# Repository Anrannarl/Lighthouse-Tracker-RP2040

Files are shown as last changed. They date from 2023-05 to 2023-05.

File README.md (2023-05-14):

# Lighthouse-Tracker-RP2040
A Lighthouse tracker based on Raspberry Pi Pico.
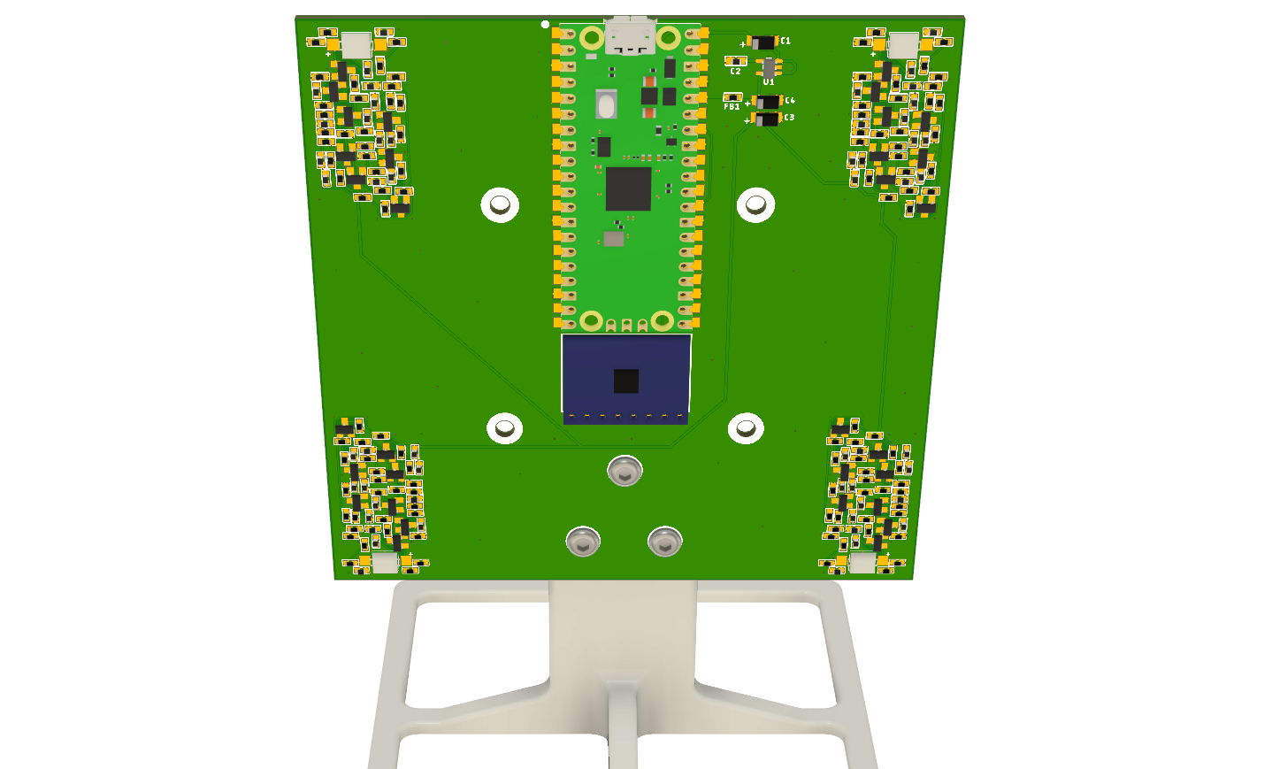
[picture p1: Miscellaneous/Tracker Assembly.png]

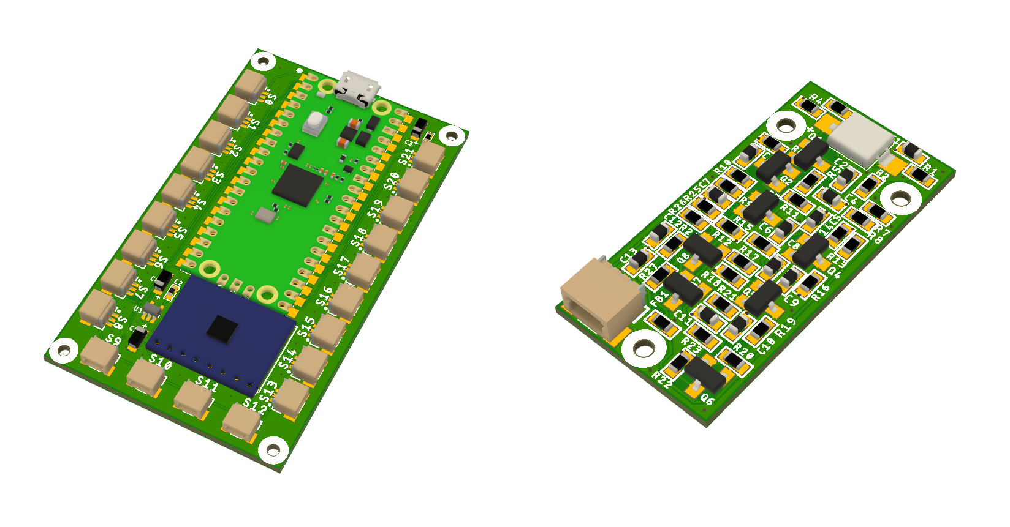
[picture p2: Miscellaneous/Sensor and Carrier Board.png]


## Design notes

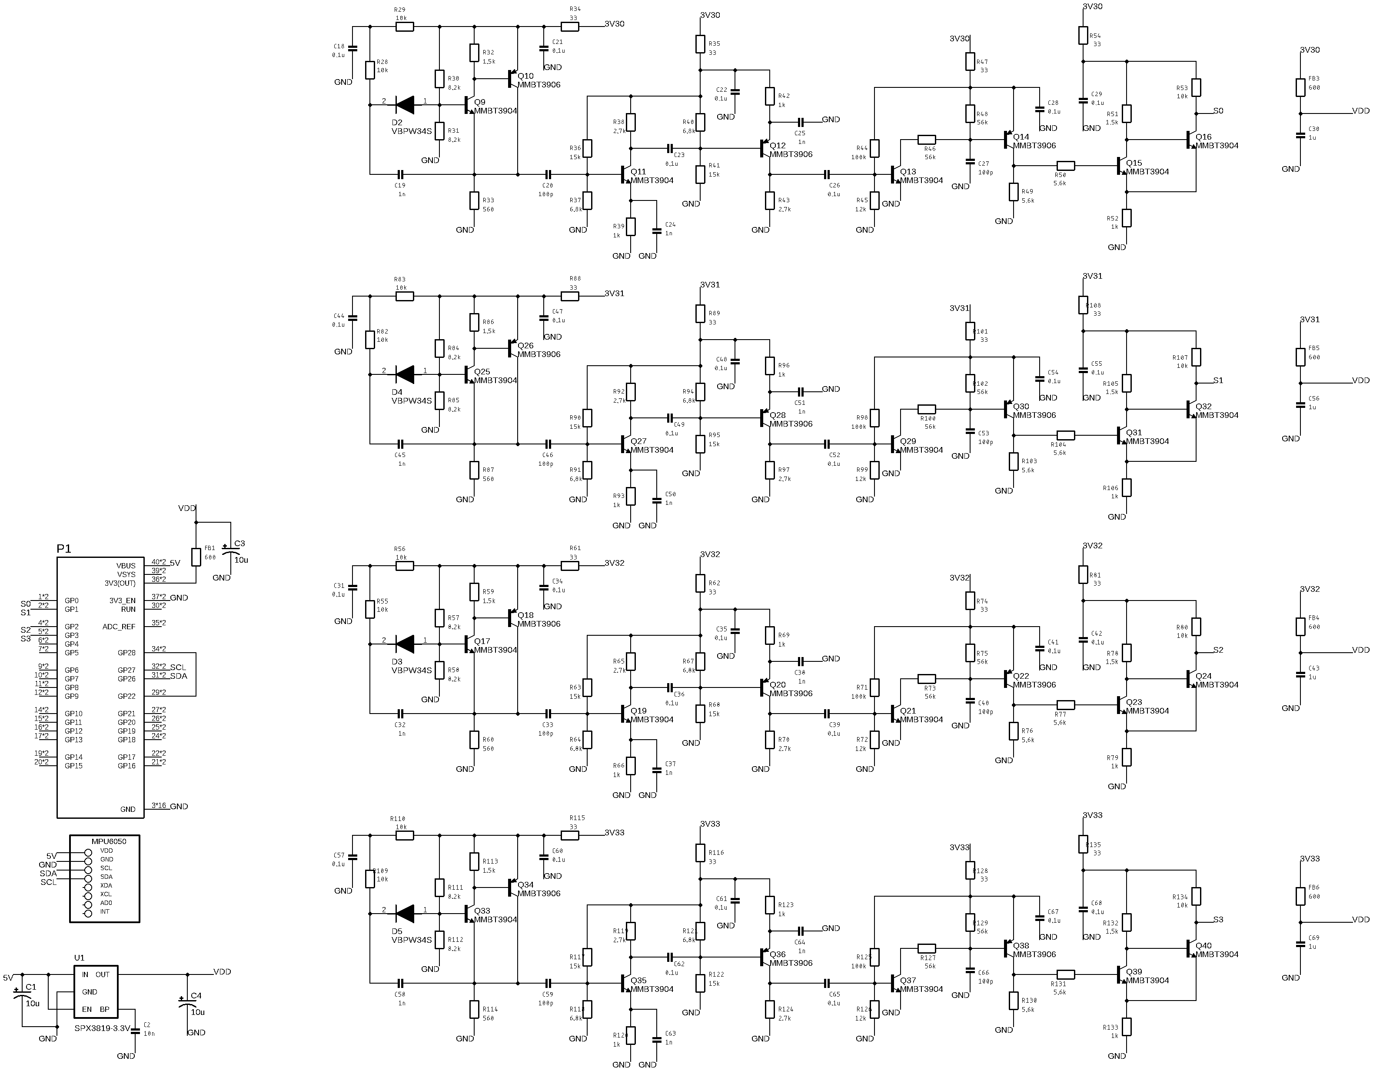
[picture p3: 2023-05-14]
Design Files/Lighthouse Tracker/Lighthouse Tracker.png

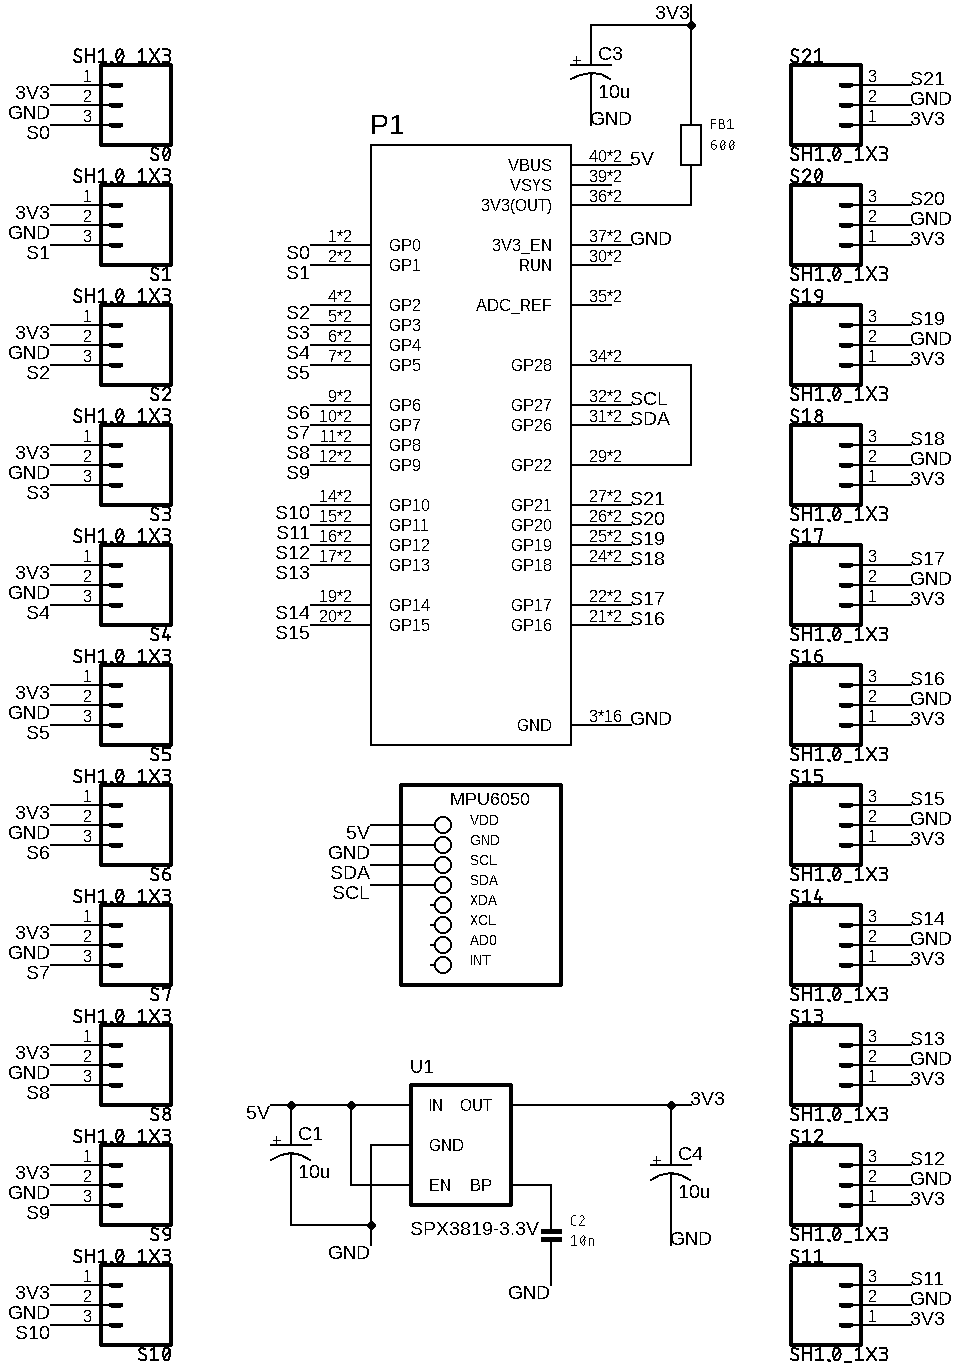
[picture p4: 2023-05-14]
Design Files/Lighthouse Sensor Carrier/Lighthouse Sensor Carrier.png

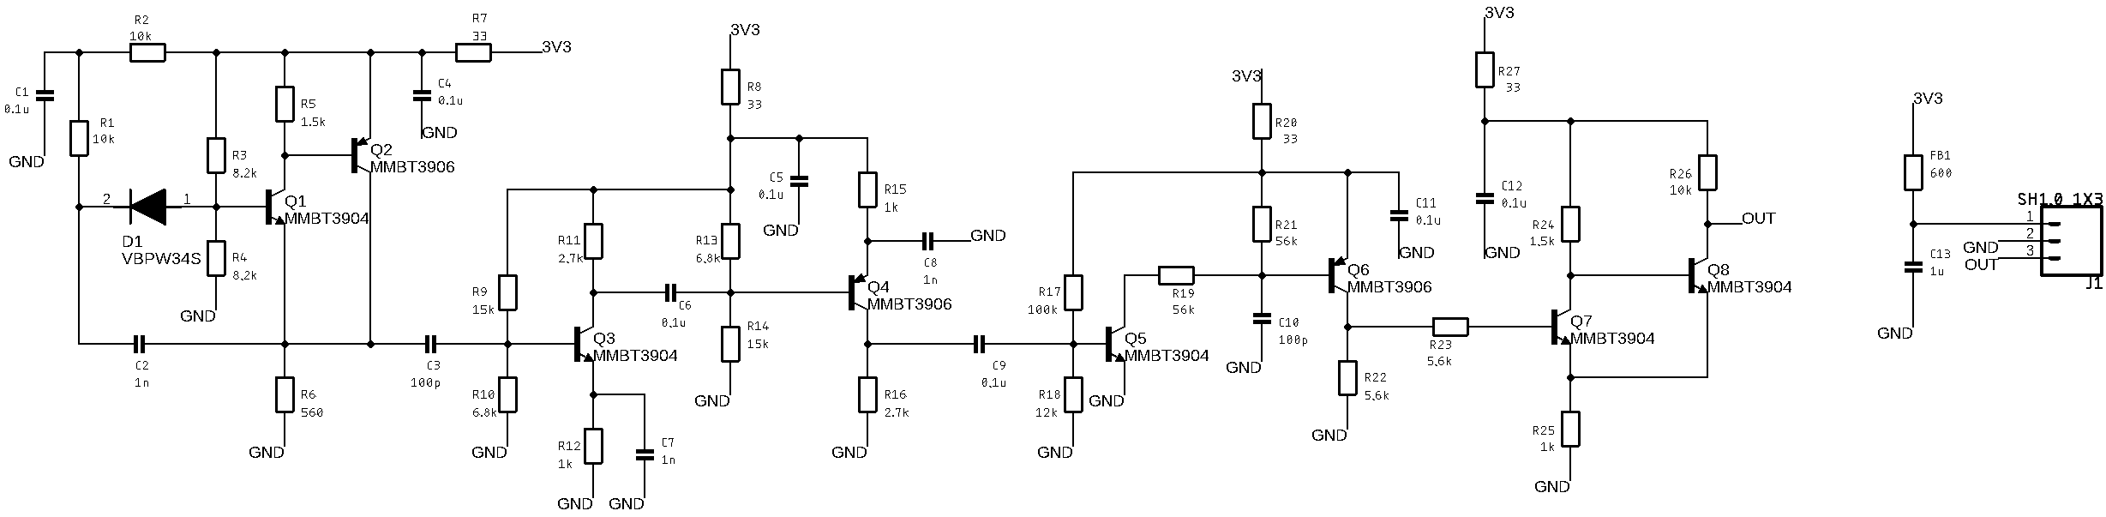
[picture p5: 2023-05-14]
Design Files/Lighthouse Sensor/Lighthouse Sensor.png

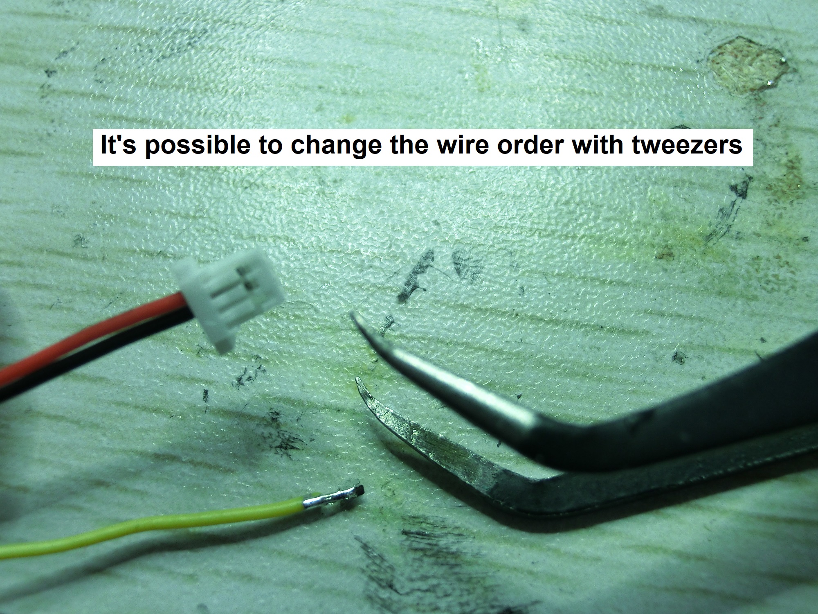
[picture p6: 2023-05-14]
Miscellaneous/Cable2.JPG

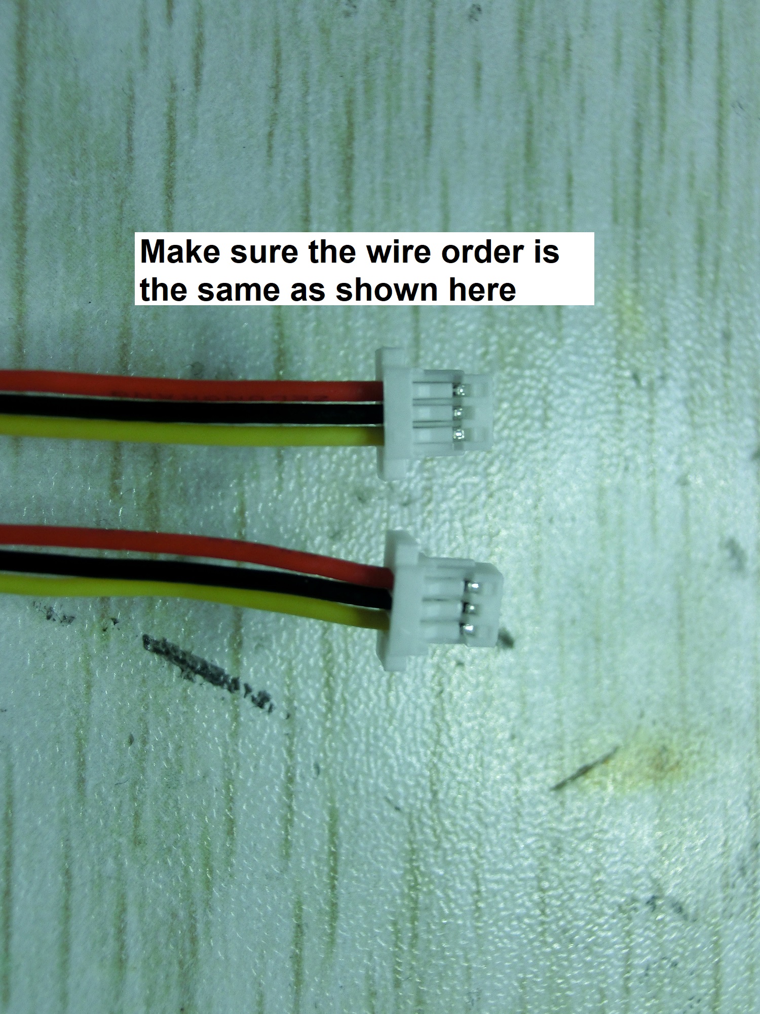
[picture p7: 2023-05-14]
Miscellaneous/Cable1.JPG

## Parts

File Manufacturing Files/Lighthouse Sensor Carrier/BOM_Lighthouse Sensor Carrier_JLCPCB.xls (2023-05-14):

Comment | Designator | Footprint | 嘉立创元件编号
10n | C2 | C0603 | C57112
10u | C1, C3, C4 | C3216 | C7171
600 | FB1 | R0603 | C1002
SPX3819-3.3V | U1 | SOT23-5 | C9055
SH1.0_1X3 | S0, S1, S2, S3, S4, S5, S6, S7, S8, S9, S10, S11, S12, S13, S14, S15, S16, S17, S18, S19, S20, S21 | 1X03_1MM_RA | C2936213

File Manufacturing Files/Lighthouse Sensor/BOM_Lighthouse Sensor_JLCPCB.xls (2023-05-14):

Comment | Designator | Footprint | 嘉立创元件编号
0.1u | C1, C4, C5, C6, C9, C11, C12 | C0603 | C14663
1.5k | R5, R24 | R0603 | C22843
100k | R17 | R0603 | C25803
100p | C3, C10 | C0603 | C14858
10k | R1, R2, R26 | R0603 | C25804
12k | R18 | R0603 | C22790
15k | R9, R14 | R0603 | C22809
1k | R12, R15, R25 | R0603 | C21190
1n | C2, C7, C8 | C0603 | C1588
1u | C13 | C0603 | C15849
2.7k | R11, R16 | R0603 | C13167
33 | R7, R8, R20, R27 | R0603 | C23140
5.6k | R22, R23 | R0603 | C23189
560 | R6 | R0603 | C23204
56k | R19, R21 | R0603 | C23206
6.8k | R10, R13 | R0603 | C23212
600 | FB1 | R0603 | C1002
8.2k | R3, R4 | R0603 | C25981
MMBT3904 | Q1, Q3, Q5, Q7, Q8 | SOT23 | C20526
MMBT3906 | Q2, Q4, Q6 | SOT23 | C2143
SH1.0_1X3 | J1 | 1X03_1MM_RA | C2936213
VBPW34S | D1 | VBPW34S | C131274

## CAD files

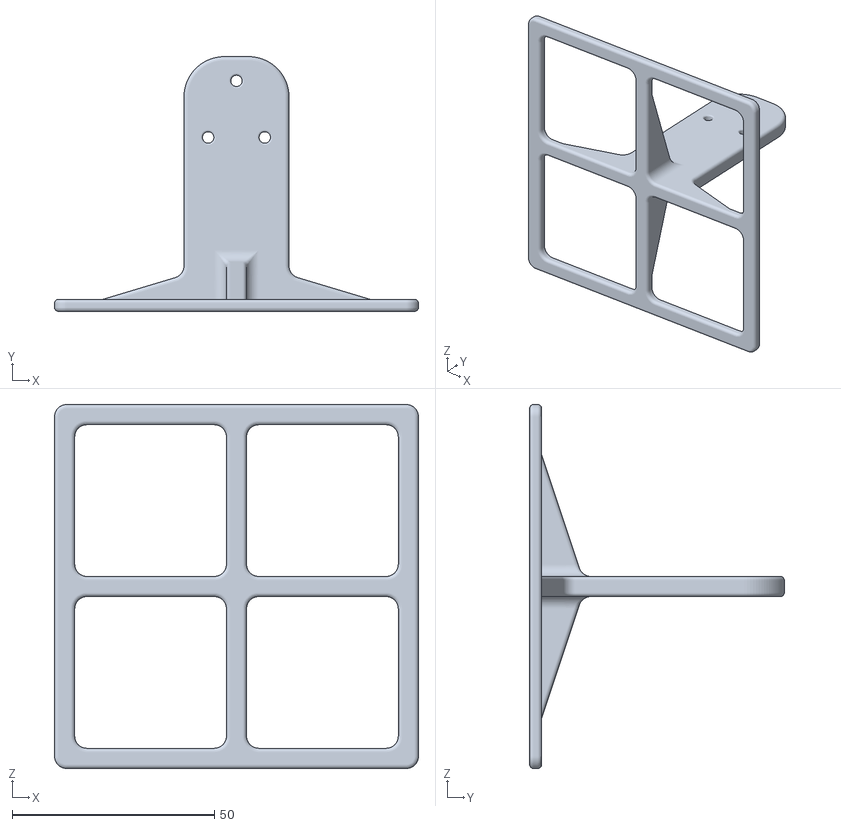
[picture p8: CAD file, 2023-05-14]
3D Models/Stand.stl
90.0 x 63.0 x 90.0

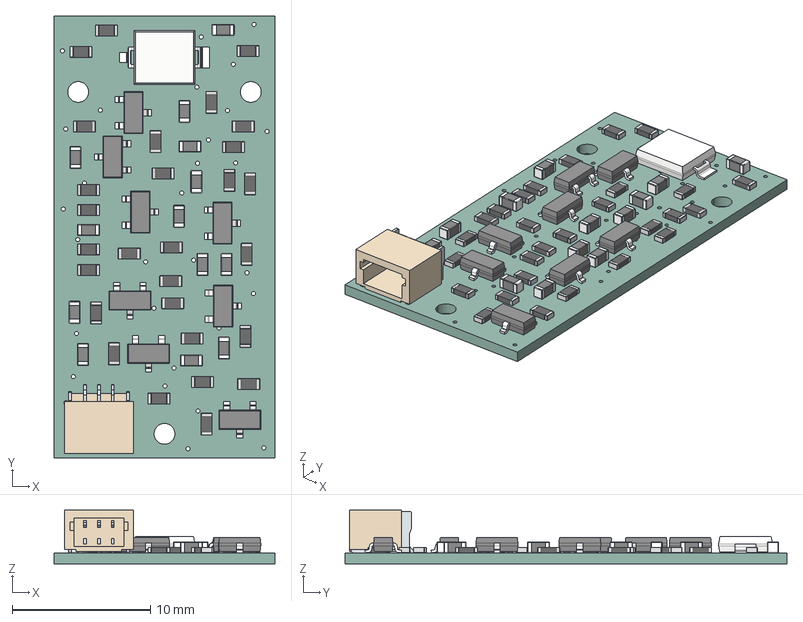
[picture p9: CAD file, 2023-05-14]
3D Models/Lighthouse Sensor.step
16.0 x 32.0 x 3.90 mm
Board
6651xx131822_PIN x 3
6651xx131822_PATTE x 2
Gehäuse x 13
Kontaktfläche x 26
R0603 x 28
SOT23-BEC x 5
SOT23-BEC (1) x 3

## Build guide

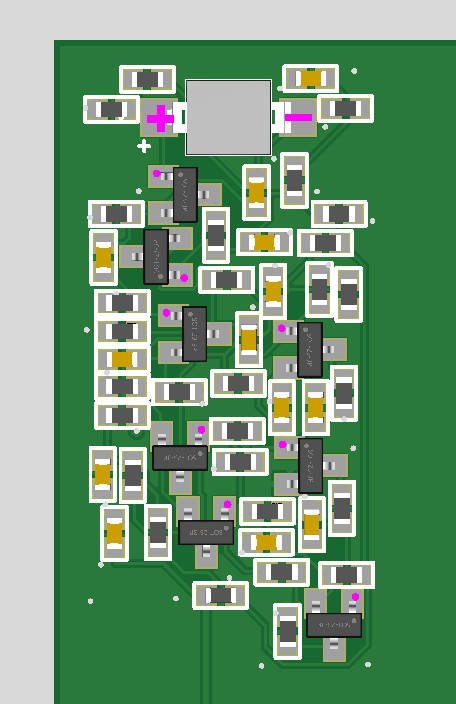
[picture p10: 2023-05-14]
Manufacturing Files/Lighthouse Tracker/Preview2.png

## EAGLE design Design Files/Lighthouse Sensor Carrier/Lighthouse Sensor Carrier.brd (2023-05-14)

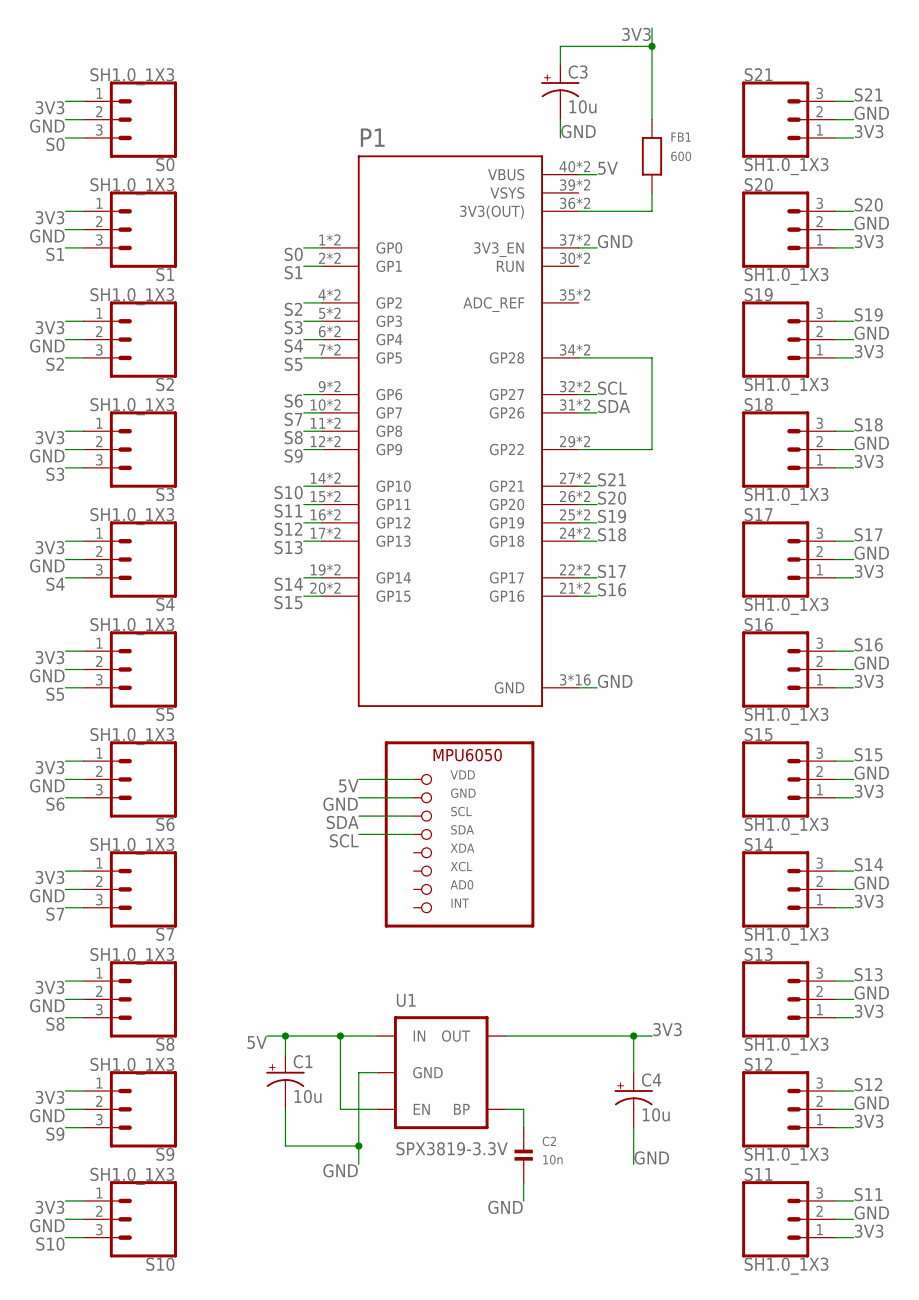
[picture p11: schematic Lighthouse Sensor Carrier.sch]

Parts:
C1, C3, C4: 10u; A/3216-18R
C2: 10n; 0603
FB1: 600; R0603
P1: RASPBERRY_PICO-NO_DEBUG; PICO-PKG-NO_DEBUG
S0, S1, S2, S3, S4, S5, S6, S7, S8, S9, S10, S11, S12, S13, S14, S15, S16, S17, S18, S19, S20, S21: SH1.0_1X3; 1X03_1MM_RA
U1: SPX3819-3.3V; SOT23-5
U$1: MPU6050BREAKOUT; MPU6050

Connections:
3V3: C3.+, C4.+, FB1.2, S0.1, S1.1, S2.1, S3.1, S4.1, S5.1, S6.1, S7.1, S8.1, S9.1, S10.1, S11.1, S12.1, S13.1, S14.1, S15.1, S16.1, S17.1, S18.1, S19.1, S20.1, S21.1, U1.5 (OUT)
5V: C1.+, P1.40 (VBUS), P1.P$40 (VBUS), U1.1 (IN), U1.3 (EN), U$1.VDD
GND: C1.-, C2.2, C3.-, C4.-, P1.3 (GND), P1.8 (GND), P1.13 (GND), P1.18 (GND), P1.23 (GND), P1.28 (GND), P1.33 (GND), P1.37 (3V3_EN), P1.38 (GND), P1.P$3 (GND), P1.P$8 (GND), P1.P$13 (GND), P1.P$18 (GND), P1.P$23 (GND), P1.P$28 (GND), P1.P$33 (GND), P1.P$37 (3V3_EN), P1.P$38 (GND), S0.2, S1.2, S2.2, S3.2, S4.2, S5.2, S6.2, S7.2, S8.2, S9.2, S10.2, S11.2, S12.2, S13.2, S14.2, S15.2, S16.2, S17.2, S18.2, S19.2, S20.2, S21.2, U1.2 (GND), U$1.GND
unnamed: C2.1, U1.4 (BP)
unnamed: FB1.1, P1.36 (3V3(OUT)), P1.P$36 (3V3(OUT))
unnamed: P1.29 (GP22), P1.34 (GP28), P1.P$29 (GP22), P1.P$34 (GP28)
S0: P1.1 (GP0), P1.P$1 (GP0), S0.3
S1: P1.2 (GP1), P1.P$2 (GP1), S1.3
S2: P1.4 (GP2), P1.P$4 (GP2), S2.3
S3: P1.5 (GP3), P1.P$5 (GP3), S3.3
S4: P1.6 (GP4), P1.P$6 (GP4), S4.3
S5: P1.7 (GP5), P1.P$7 (GP5), S5.3
S6: P1.9 (GP6), P1.P$9 (GP6), S6.3
S7: P1.10 (GP7), P1.P$10 (GP7), S7.3
S8: P1.11 (GP8), P1.P$11 (GP8), S8.3
S9: P1.12 (GP9), P1.P$12 (GP9), S9.3
S10: P1.14 (GP10), P1.P$14 (GP10), S10.3
S11: P1.15 (GP11), P1.P$15 (GP11), S11.3
S12: P1.16 (GP12), P1.P$16 (GP12), S12.3
S13: P1.17 (GP13), P1.P$17 (GP13), S13.3
S14: P1.19 (GP14), P1.P$19 (GP14), S14.3
S15: P1.20 (GP15), P1.P$20 (GP15), S15.3
S16: P1.21 (GP16), P1.P$21 (GP16), S16.3
S17: P1.22 (GP17), P1.P$22 (GP17), S17.3
S18: P1.24 (GP18), P1.P$24 (GP18), S18.3
S19: P1.25 (GP19), P1.P$25 (GP19), S19.3
S20: P1.26 (GP20), P1.P$26 (GP20), S20.3
S21: P1.27 (GP21), P1.P$27 (GP21), S21.3
SCL: P1.32 (GP27), P1.P$32 (GP27), U$1.SDA
SDA: P1.31 (GP26), P1.P$31 (GP26), U$1.SCL
VSYS: P1.39 (VSYS), P1.P$39 (VSYS)

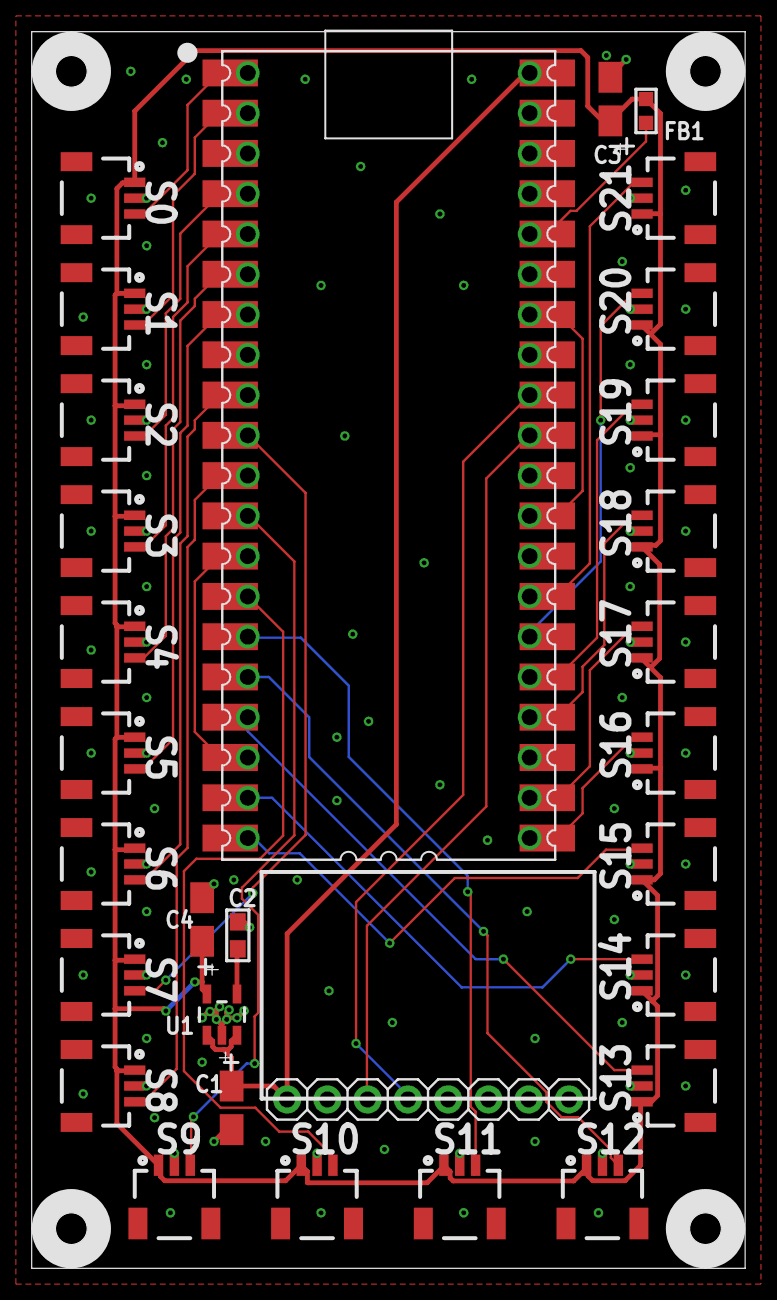
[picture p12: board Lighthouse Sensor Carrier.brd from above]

Board: 2 copper layers, 45.0 x 78.0 mm, 30 parts (0 on the bottom side), 31 nets.

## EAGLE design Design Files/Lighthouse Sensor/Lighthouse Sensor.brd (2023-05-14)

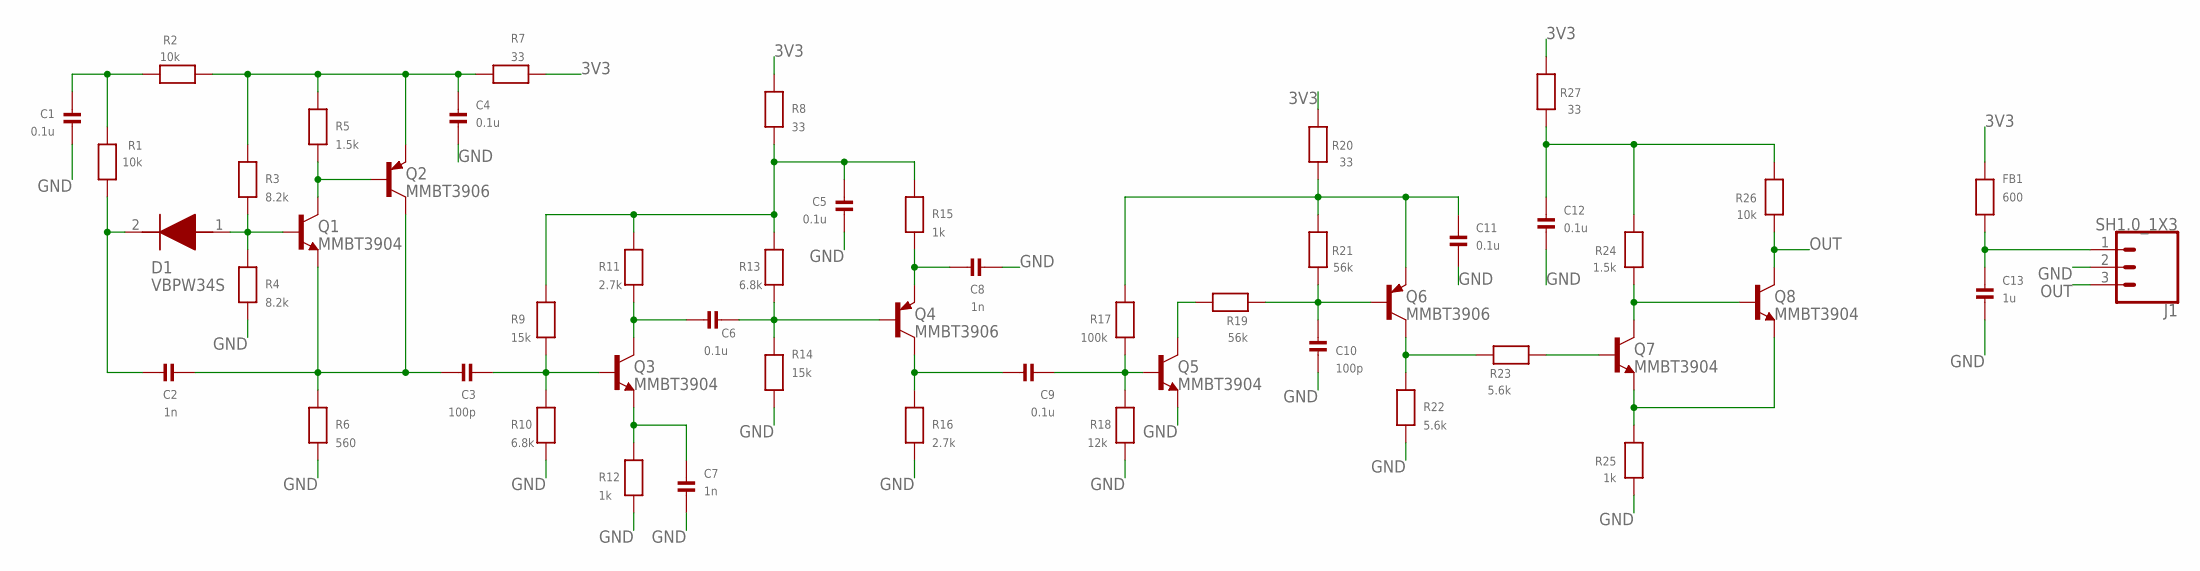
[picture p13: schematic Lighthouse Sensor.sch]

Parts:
C1, C4, C5, C6, C9, C11, C12: 0.1u; C0603
C2, C7, C8: 1n; C0603
C3, C10: 100p; C0603
C13: 1u; C0603
D1: VBPW34S
FB1: 600; R0603
J1: SH1.0_1X3; 1X03_1MM_RA
Q1, Q3, Q5, Q7, Q8: MMBT3904; SOT23-BEC
Q2, Q4, Q6: MMBT3906; SOT23-BEC
R1, R2, R26: 10k; R0603
R3, R4: 8.2k; R0603
R5, R24: 1.5k; R0603
R6: 560; R0603
R7, R8, R20, R27: 33; R0603
R9, R14: 15k; R0603
R10, R13: 6.8k; R0603
R11, R16: 2.7k; R0603
R12, R15, R25: 1k; R0603
R17: 100k; R0603
R18: 12k; R0603
R19, R21: 56k; R0603
R22, R23: 5.6k; R0603

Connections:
3V3: FB1.2, R7.2, R8.1, R20.2, R27.2
GND: C1.1, C4.1, C5.2, C7.2, C8.2, C10.1, C11.1, C12.1, C13.1, J1.2, Q5.E, R4.2, R6.2, R10.2, R12.2, R14.2, R16.2, R18.2, R22.1, R25.2
unnamed: C1.2, R1.2, R2.2
unnamed: C2.1, D1.2 (K), R1.1
unnamed: D1.1 (A), Q1.B, R3.2, R4.1
unnamed: C4.2, Q2.E, R2.1, R3.1, R5.1, R7.1
unnamed: Q1.C, Q2.B, R5.2
unnamed: C11.2, Q6.E, R17.1, R20.1, R21.2
unnamed: C5.1, R8.2, R9.1, R11.1, R13.1, R15.1
unnamed: C3.2, Q3.B, R9.2, R10.1
unnamed: C2.2, C3.1, Q1.E, Q2.C, R6.1
unnamed: C6.2, Q4.B, R13.2, R14.1
unnamed: C6.1, Q3.C, R11.2
unnamed: C7.1, Q3.E, R12.1
unnamed: C9.2, Q5.B, R17.2, R18.1
unnamed: C8.1, Q4.E, R15.2
unnamed: C9.1, Q4.C, R16.1
unnamed: Q6.C, R22.2, R23.2
unnamed: C10.2, Q6.B, R19.2, R21.1
unnamed: Q5.C, R19.1
unnamed: Q7.B, R23.1
unnamed: Q7.E, Q8.E, R25.1
unnamed: Q7.C, Q8.B, R24.2
unnamed: C13.2, FB1.1, J1.1
unnamed: C12.2, R24.1, R26.1, R27.1
OUT: J1.3, Q8.C, R26.2

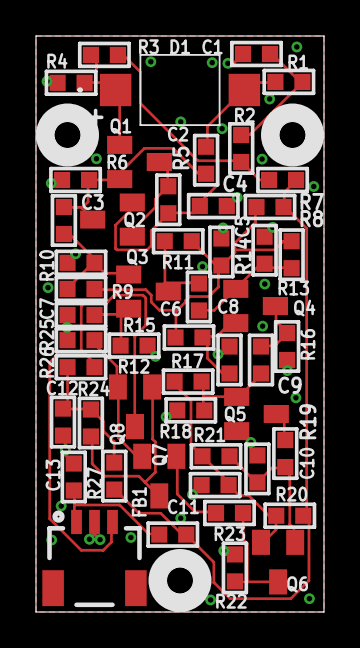
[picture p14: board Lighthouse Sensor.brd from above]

Board: 2 copper layers, 16.0 x 32.0 mm, 51 parts (0 on the bottom side), 26 nets.

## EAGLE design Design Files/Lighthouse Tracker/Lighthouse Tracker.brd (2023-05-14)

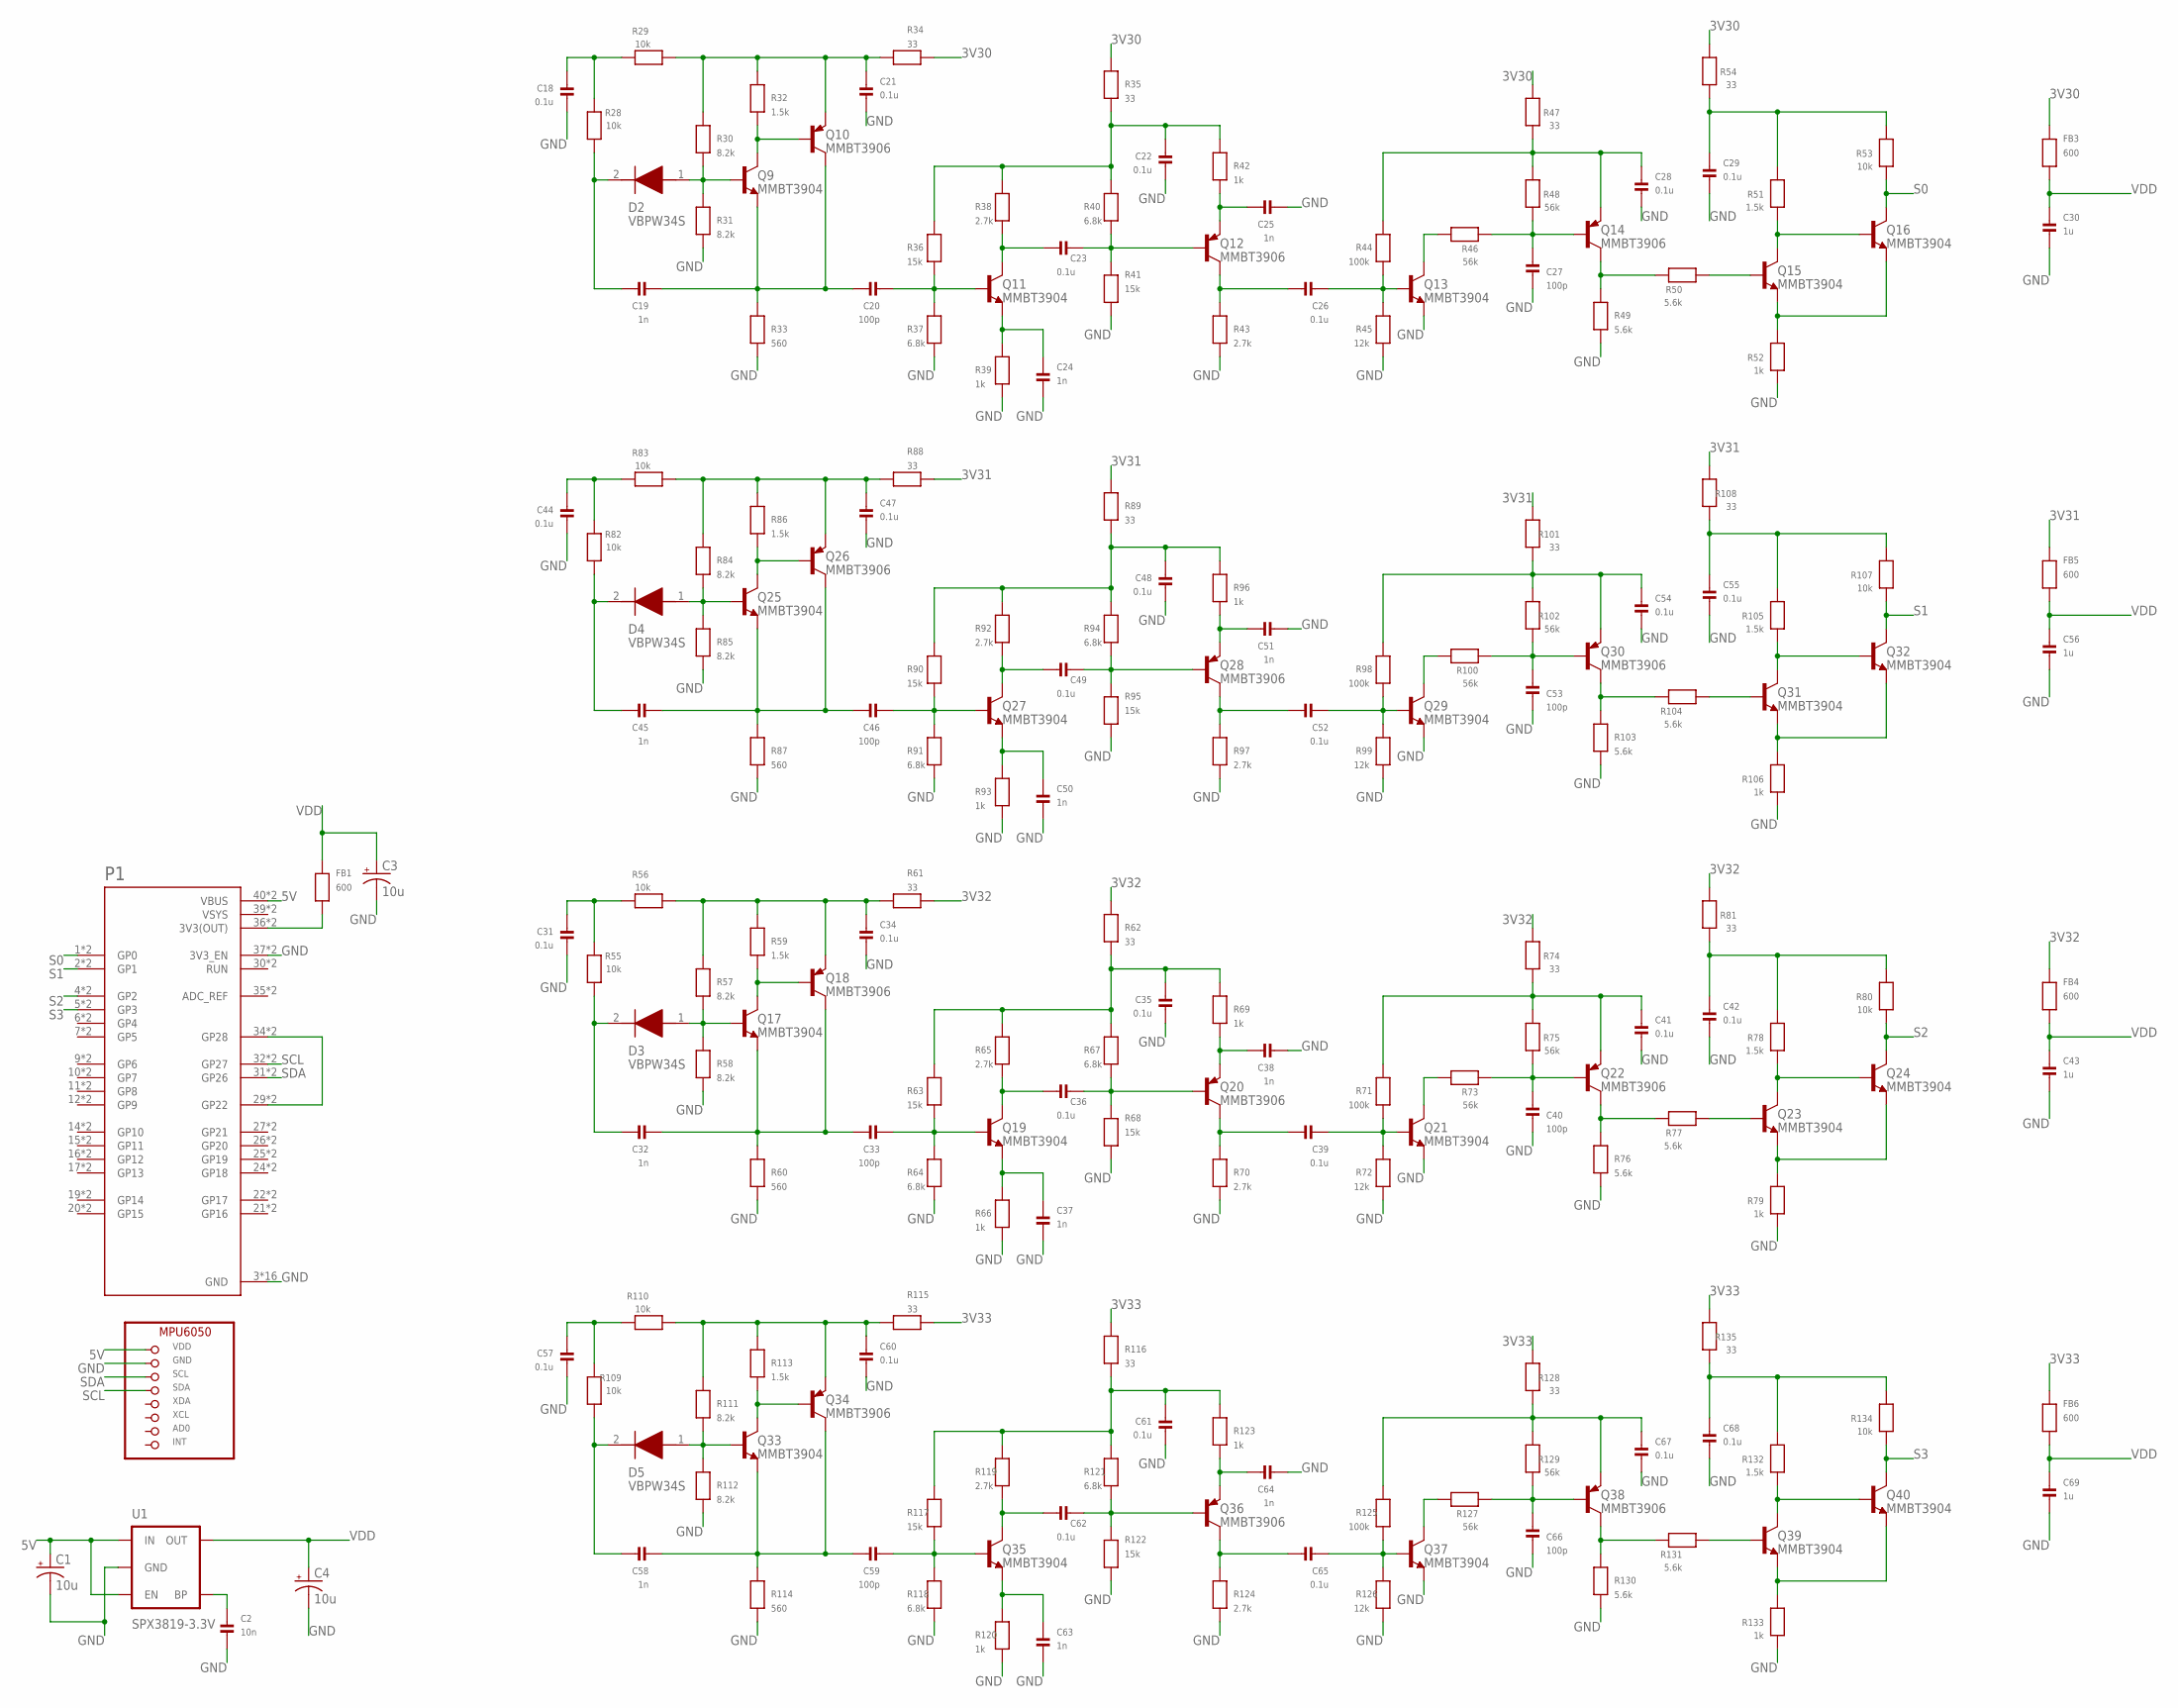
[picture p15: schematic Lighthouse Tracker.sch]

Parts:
B1: MPU6050BREAKOUT; MPU6050
C1, C3, C4: 10u; A/3216-18R
C2: 10n; 0603
C18, C21, C22, C23, C26, C28, C29, C31, C34, C35, C36, C39, C41, C42, C44, C47, C48, C49, C52, C54, C55, C57, C60, C61, C62, C65, C67, C68: 0.1u; C0603
C19, C24, C25, C32, C37, C38, C45, C50, C51, C58, C63, C64: 1n; C0603
C20, C27, C33, C40, C46, C53, C59, C66: 100p; C0603
C30, C43, C56, C69: 1u; C0603
D2, D3, D4, D5: VBPW34S
FB1, FB3, FB4, FB5, FB6: 600; R0603
P1: RASPBERRY_PICO-NO_DEBUG; PICO-PKG-NO_DEBUG
Q9, Q11, Q13, Q15, Q16, Q17, Q19, Q21, Q23, Q24, Q25, Q27, Q29, Q31, Q32, Q33, Q35, Q37, Q39, Q40: MMBT3904; SOT23-BEC
Q10, Q12, Q14, Q18, Q20, Q22, Q26, Q28, Q30, Q34, Q36, Q38: MMBT3906; SOT23-BEC
R28, R29, R53, R55, R56, R80, R82, R83, R107, R109, R110, R134: 10k; R0603
R30, R31, R57, R58, R84, R85, R111, R112: 8.2k; R0603
R32, R51, R59, R78, R86, R105, R113, R132: 1.5k; R0603
R33, R60, R87, R114: 560; R0603
R34, R35, R47, R54, R61, R62, R74, R81, R88, R89, R101, R108, R115, R116, R128, R135: 33; R0603
R36, R41, R63, R68, R90, R95, R117, R122: 15k; R0603
R37, R40, R64, R67, R91, R94, R118, R121: 6.8k; R0603
R38, R43, R65, R70, R92, R97, R119, R124: 2.7k; R0603
R39, R42, R52, R66, R69, R79, R93, R96, R106, R120, R123, R133: 1k; R0603
R44, R71, R98, R125: 100k; R0603
R45, R72, R99, R126: 12k; R0603
R46, R48, R73, R75, R100, R102, R127, R129: 56k; R0603
R49, R50, R76, R77, R103, R104, R130, R131: 5.6k; R0603
U1: SPX3819-3.3V; SOT23-5

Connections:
3V30: FB3.2, R34.2, R35.1, R47.2, R54.2
3V31: FB5.2, R88.2, R89.1, R101.2, R108.2
3V32: FB4.2, R61.2, R62.1, R74.2, R81.2
3V33: FB6.2, R115.2, R116.1, R128.2, R135.2
5V: B1.VDD, C1.+, P1.40 (VBUS), P1.P$40 (VBUS), U1.1 (IN), U1.3 (EN)
GND: B1.GND, C1.-, C2.2, C3.-, C4.-, C18.1, C21.1, C22.2, C24.2, C25.2, C27.1, C28.1, C29.1, C30.1, C31.1, C34.1, C35.2, C37.2, C38.2, C40.1, C41.1, C42.1, C43.1, C44.1, C47.1, C48.2, C50.2, C51.2, C53.1, C54.1, C55.1, C56.1, C57.1, C60.1, C61.2, C63.2, C64.2, C66.1, C67.1, C68.1, C69.1, P1.3 (GND), P1.8 (GND), P1.13 (GND), P1.18 (GND), P1.23 (GND), P1.28 (GND), P1.33 (GND), P1.37 (3V3_EN), P1.38 (GND), P1.P$3 (GND), P1.P$8 (GND), P1.P$13 (GND), P1.P$18 (GND), P1.P$23 (GND), P1.P$28 (GND), P1.P$33 (GND), P1.P$37 (3V3_EN), P1.P$38 (GND), Q13.E, Q21.E, Q29.E, Q37.E, R31.2, R33.2, R37.2, R39.2, R41.2, R43.2, R45.2, R49.1, R52.2, R58.2, R60.2, R64.2, R66.2, R68.2, R70.2, R72.2, R76.1, R79.2, R85.2, R87.2, R91.2, R93.2, R95.2, R97.2, R99.2, R103.1, R106.2, R112.2, R114.2, R118.2, R120.2, R122.2, R124.2, R126.2, R130.1, R133.2, U1.2 (GND)
unnamed: C2.1, U1.4 (BP)
unnamed: FB1.1, P1.36 (3V3(OUT)), P1.P$36 (3V3(OUT))
unnamed: P1.29 (GP22), P1.34 (GP28), P1.P$29 (GP22), P1.P$34 (GP28)
unnamed: C18.2, R28.2, R29.2
unnamed: C19.1, D2.2 (K), R28.1
unnamed: D2.1 (A), Q9.B, R30.2, R31.1
unnamed: C21.2, Q10.E, R29.1, R30.1, R32.1, R34.1
unnamed: Q9.C, Q10.B, R32.2
unnamed: C19.2, C20.1, Q9.E, Q10.C, R33.1
unnamed: C22.1, R35.2, R36.1, R38.1, R40.1, R42.1
unnamed: C20.2, Q11.B, R36.2, R37.1
unnamed: C23.1, Q11.C, R38.2
unnamed: C24.1, Q11.E, R39.1
unnamed: C23.2, Q12.B, R40.2, R41.1
unnamed: C25.1, Q12.E, R42.2
unnamed: C26.1, Q12.C, R43.1
unnamed: C26.2, Q13.B, R44.2, R45.1
unnamed: C28.2, Q14.E, R44.1, R47.1, R48.2
unnamed: C27.2, Q14.B, R46.2, R48.1
unnamed: Q13.C, R46.1
unnamed: Q14.C, R49.2, R50.2
unnamed: Q15.B, R50.1
unnamed: Q15.E, Q16.E, R52.1
unnamed: Q15.C, Q16.B, R51.2
unnamed: C29.2, R51.1, R53.1, R54.1
unnamed: C31.2, R55.2, R56.2
unnamed: C32.1, D3.2 (K), R55.1
unnamed: D3.1 (A), Q17.B, R57.2, R58.1
unnamed: C34.2, Q18.E, R56.1, R57.1, R59.1, R61.1
unnamed: Q17.C, Q18.B, R59.2
unnamed: C32.2, C33.1, Q17.E, Q18.C, R60.1
unnamed: C35.1, R62.2, R63.1, R65.1, R67.1, R69.1
unnamed: C33.2, Q19.B, R63.2, R64.1
unnamed: C36.1, Q19.C, R65.2
unnamed: C37.1, Q19.E, R66.1
unnamed: C36.2, Q20.B, R67.2, R68.1
unnamed: C38.1, Q20.E, R69.2
unnamed: C39.1, Q20.C, R70.1
unnamed: C39.2, Q21.B, R71.2, R72.1
unnamed: C41.2, Q22.E, R71.1, R74.1, R75.2
unnamed: C40.2, Q22.B, R73.2, R75.1
unnamed: Q21.C, R73.1
unnamed: Q22.C, R76.2, R77.2
unnamed: Q23.B, R77.1
unnamed: Q23.E, Q24.E, R79.1
unnamed: Q23.C, Q24.B, R78.2
unnamed: C42.2, R78.1, R80.1, R81.1
unnamed: C44.2, R82.2, R83.2
unnamed: C45.1, D4.2 (K), R82.1
unnamed: D4.1 (A), Q25.B, R84.2, R85.1
unnamed: C47.2, Q26.E, R83.1, R84.1, R86.1, R88.1
unnamed: Q25.C, Q26.B, R86.2
unnamed: C45.2, C46.1, Q25.E, Q26.C, R87.1
unnamed: C48.1, R89.2, R90.1, R92.1, R94.1, R96.1
unnamed: C46.2, Q27.B, R90.2, R91.1
unnamed: C49.1, Q27.C, R92.2
unnamed: C50.1, Q27.E, R93.1
unnamed: C49.2, Q28.B, R94.2, R95.1
unnamed: C51.1, Q28.E, R96.2
unnamed: C52.1, Q28.C, R97.1
unnamed: C52.2, Q29.B, R98.2, R99.1
unnamed: C54.2, Q30.E, R98.1, R101.1, R102.2
unnamed: C53.2, Q30.B, R100.2, R102.1
unnamed: Q29.C, R100.1
unnamed: Q30.C, R103.2, R104.2
unnamed: Q31.B, R104.1
unnamed: Q31.E, Q32.E, R106.1
unnamed: Q31.C, Q32.B, R105.2
unnamed: C55.2, R105.1, R107.1, R108.1
unnamed: C57.2, R109.2, R110.2
unnamed: C58.1, D5.2 (K), R109.1
unnamed: D5.1 (A), Q33.B, R111.2, R112.1
unnamed: C60.2, Q34.E, R110.1, R111.1, R113.1, R115.1
unnamed: Q33.C, Q34.B, R113.2
unnamed: C58.2, C59.1, Q33.E, Q34.C, R114.1
unnamed: C61.1, R116.2, R117.1, R119.1, R121.1, R123.1
unnamed: C59.2, Q35.B, R117.2, R118.1
unnamed: C62.1, Q35.C, R119.2
unnamed: C63.1, Q35.E, R120.1
unnamed: C62.2, Q36.B, R121.2, R122.1
unnamed: C64.1, Q36.E, R123.2
unnamed: C65.1, Q36.C, R124.1
unnamed: C65.2, Q37.B, R125.2, R126.1
unnamed: C67.2, Q38.E, R125.1, R128.1, R129.2
unnamed: C66.2, Q38.B, R127.2, R129.1
unnamed: Q37.C, R127.1
unnamed: Q38.C, R130.2, R131.2
unnamed: Q39.B, R131.1
unnamed: Q39.E, Q40.E, R133.1
unnamed: Q39.C, Q40.B, R132.2
unnamed: C68.2, R132.1, R134.1, R135.1
S0: P1.1 (GP0), P1.P$1 (GP0), Q16.C, R53.2
S1: P1.2 (GP1), P1.P$2 (GP1), Q32.C, R107.2
S2: P1.4 (GP2), P1.P$4 (GP2), Q24.C, R80.2
S3: P1.5 (GP3), P1.P$5 (GP3), Q40.C, R134.2
SCL: B1.SDA, P1.32 (GP27), P1.P$32 (GP27)
SDA: B1.SCL, P1.31 (GP26), P1.P$31 (GP26)
VDD: C3.+, C4.+, C30.2, C43.2, C56.2, C69.2, FB1.2, FB3.1, FB4.1, FB5.1, FB6.1, U1.5 (OUT)
VSYS: P1.39 (VSYS), P1.P$39 (VSYS)

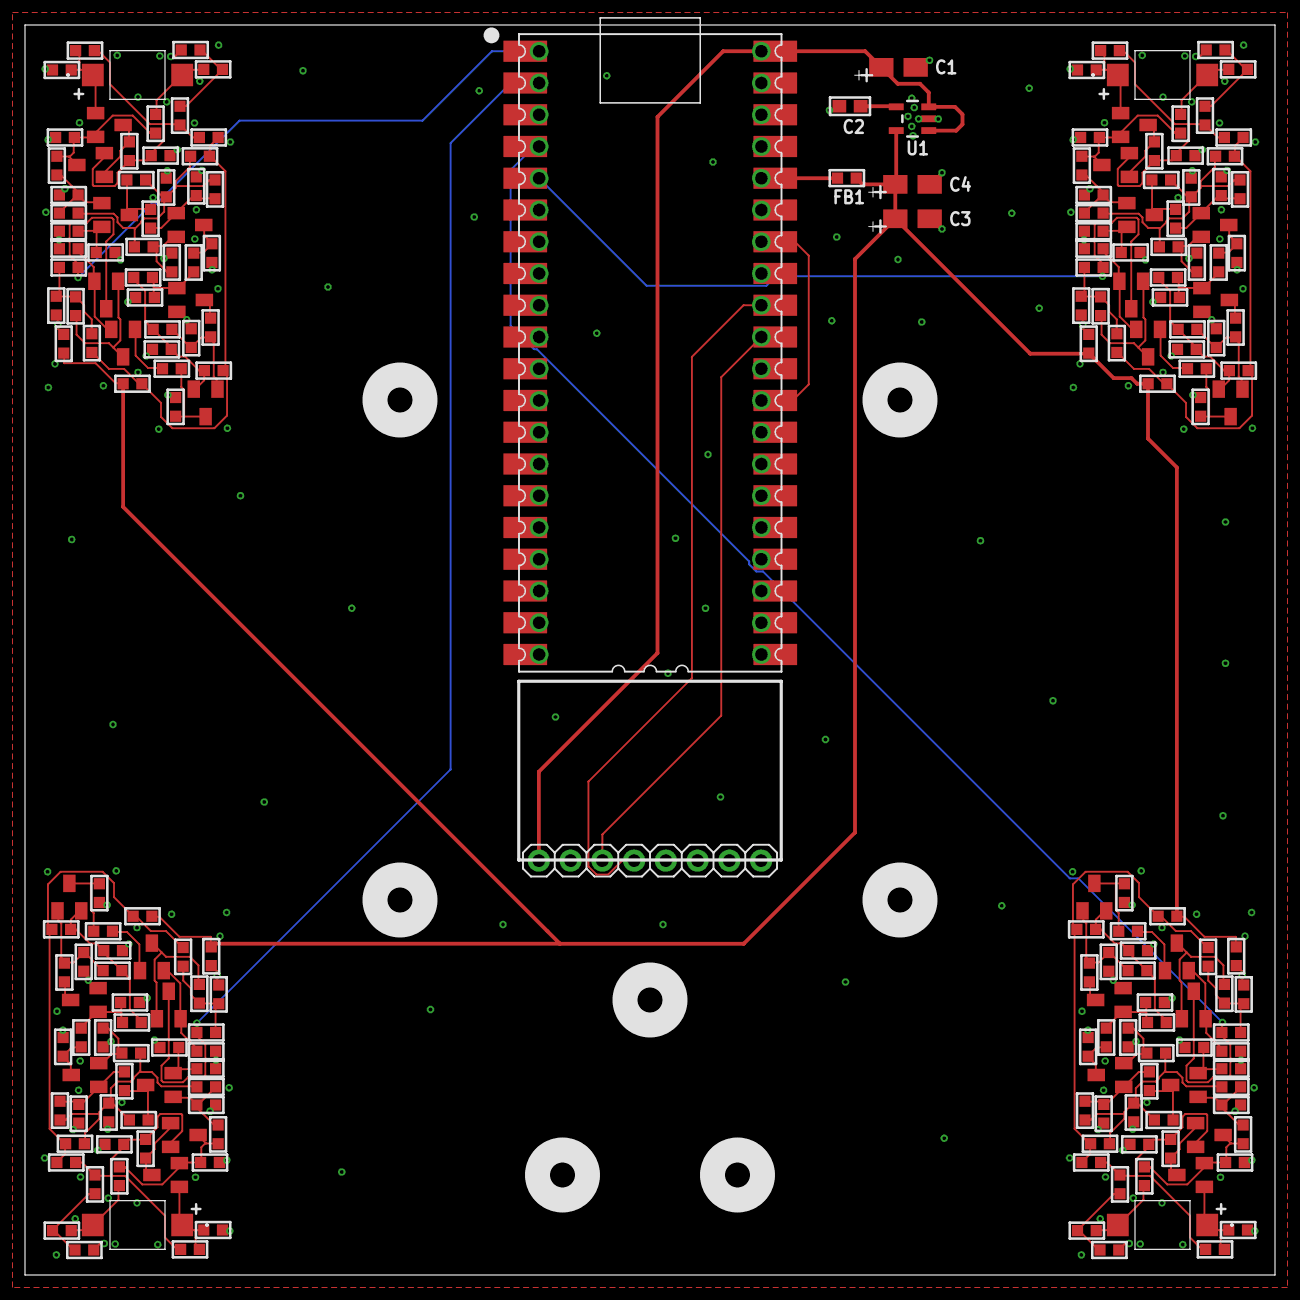
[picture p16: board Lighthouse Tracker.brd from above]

Board: 2 copper layers, 100.0 x 100.0 mm, 208 parts (0 on the bottom side), 105 nets.

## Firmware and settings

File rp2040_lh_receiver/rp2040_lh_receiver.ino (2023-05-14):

// A simple program using PIO to read lighthouse sensor outputs
// It can support up to 22 sensors
// RP2040 Arduino core is used https://github.com/earlephilhower/arduino-pico
// The CPU clock is set to 250Mhz(overclock)
// I suggest using the official Raspberry Pi Pico board
// The system power supply must be a low noise linear regulator
// The SMPS on the Raspberry Pi Pico board is disabled

// Links you might find useful
// Pico C SDK document https://www.raspberrypi.com/documentation/pico-sdk/
// PIO examples https://github.com/GitJer/Some_RPI-Pico_stuff
// RP2040 logic analyzer https://github.com/gusmanb/logicanalyzer
// Raspberry Pi Pico datasheet https://datasheets.raspberrypi.com/pico/pico-datasheet.pdf
// RP2040 datasheet https://datasheets.raspberrypi.com/rp2040/rp2040-datasheet.pdf

// Some open-source projects
// libsurvive https://github.com/cntools/libsurvive
// LighthouseRedox https://github.com/nairol/LighthouseRedox
// HTC vive lighthouse custom tracking https://hackaday.io/project/19570-htc-vive-lighthouse-custom-tracking
// bitcraze Lighthouse https://www.bitcraze.io/documentation/lighthouse/
// HiveTracker https://hackaday.io/project/160182-hivetracker
// VIVE POSITION SENSOR https://hacks.esar.org.uk/vive-position-sensor/ https://github.com/esar/vivepos
// vive-tracker https://github.com/arenibProjects/vive-tracker
// Homebrew interface for the HTC v1 Lighthouses https://trmm.net/Lighthouse/
// Position Aware Devices https://blog.crashspace.org/2016/12/position-aware-device/
// DIY Position Tracking https://github.com/ashtuchkin/vive-diy-position-sensor
// EE267 6-DOF Pose Tracking with the VRduino https://stanford.edu/class/ee267/notes/ee267_notes_tracking.pdf
// EE267 https://github.com/kingofleaves/Lighthouse-Tracking https://github.com/mohism-ai-lab/EE267


#include "pico/stdlib.h"
#include "pico/util/queue.h"
#include "hardware/pio.h"
#include "hardware/dma.h"
#include "sensor_handler.pio.h"

// no need to change
#define SENSOR_COUNT 22
// it's possible to use lower buffer size to reduce latency
// try to find a value that doesn't crash the program or cause data corruption
// 16 is a safe value even for the worst scenario(22 coplanar sensors)
#define SM_BUFFER_SIZE 16
// use chained DMA to move data from SM to buffer automatically
// when the first DMA channel finishes, it triggers the second one right away and flags an interrupt
// CPU is used to reconfigure the finished DMA channel and move the data from the finished buffer to a queue
// five chained DMA for each SM
#define SM_DMA_COUNT 5
#define SM_QUEUE_LIMIT 200

PIO pio = pio0;
const uint32_t sm0 = 0, sm1 = 1; // sm0 and sm1 are used
const uint32_t sm0_clkdiv = 4, sm1_clkdiv = 4; // clkdiv = 4 to run SM at 1/4 CPU clock
// one count equals 3 * PIO tick (see the PIO program for more details)
// 48ns for the default setup
#define PIO_CYCLE_TIME 48
uint32_t sm0_offset, sm1_offset;
const uint32_t in_base = 0, sideset_base = 28, jmp_pin = 22;
// pin0 to pin 21 are used to read sensor outputs
// pin28 is assigned to sm0, pin22 is assigned to sm1
// pin28 is connected to pin22, it is used to trigger sm1 from sm0
// unless you design your onw hardware with RP2040, avoid using pin23(SMPS PWM mode) pin24(voltage monitor) pin25(LED)
// read Raspberry Pi Pico datasheet for more details
// to use more than 22 sensors, you need to modify the PIO program
// pin26(I2C1 SDA) and pin27(I2C1 SCL) are reserved for mpu6050

// two state machines
uint32_t sm_buffer[2][SM_DMA_COUNT][SM_BUFFER_SIZE];
int32_t dma_chan_sm[2][SM_DMA_COUNT];
dma_channel_config dma_conf_sm[2][SM_DMA_COUNT];
volatile bool sm_buffer_full[SM_DMA_COUNT];

queue_t sm0_queue;
queue_t sm1_queue;

queue_t output_queue;

struct sensor_info
{
  bool last_level;
  uint32_t time_elapsed;
};
sensor_info photosensor[SENSOR_COUNT];

struct sensor_output
{
  uint32_t sensor_id;
  bool logic_level;
  uint32_t pulse_width;
};

//core0
void setup()
{
  Serial.begin(115200);
}
void loop()
{
  while (!queue_is_empty(&sm0_queue) && !queue_is_empty(&sm1_queue))
  {
    uint32_t sm0_temp, sm1_temp, time_ns;
    queue_try_remove(&sm0_queue, &sm0_temp);
    queue_try_remove(&sm1_queue, &sm1_temp);
    time_ns = sm1_temp * PIO_CYCLE_TIME;
    for (uint32_t sensor_i = 0; sensor_i < SENSOR_COUNT; sensor_i++)
    {
      bool bit_temp = (sm0_temp << (SENSOR_COUNT - 1 - sensor_i)) >> 31;
      photosensor[sensor_i].time_elapsed += time_ns;
      if (bit_temp != photosensor[sensor_i].last_level)
      {
        sensor_output output_temp;
        output_temp.sensor_id = sensor_i;
        output_temp.logic_level = photosensor[sensor_i].last_level;
        output_temp.pulse_width = photosensor[sensor_i].time_elapsed;
        queue_try_add(&output_queue, &output_temp);
        photosensor[sensor_i].last_level = bit_temp;
        photosensor[sensor_i].time_elapsed = 0;
      }
    }
  }

  // print the sensor ID and time between rising/falling edges
  while (!queue_is_empty(&output_queue))
  {
    sensor_output output_temp;
    queue_try_remove(&output_queue, &output_temp);
    Serial.print(output_temp.sensor_id); Serial.print(" ");
    //Serial.print(output_temp.logic_level); Serial.print(" "); // use to verify sensor output, not necessary
    Serial.println(float(output_temp.pulse_width) / 1000); // output in microseconds
  }
}

//core1
void setup1()
{
  queue_init(&sm0_queue, sizeof(uint32_t), SM_QUEUE_LIMIT);
  queue_init(&sm1_queue, sizeof(uint32_t), SM_QUEUE_LIMIT);

  queue_init(&output_queue, sizeof(sensor_output), SM_QUEUE_LIMIT);

  sm0_offset = pio_add_program(pio, &level_monitor_program);
  sm1_offset = pio_add_program(pio, &time_stamp_program);

  pio_sm_config c_sm0 = level_monitor_program_get_default_config(sm0_offset);
  pio_sm_config c_sm1 = time_stamp_program_get_default_config(sm1_offset);

  sm_config_set_clkdiv(&c_sm0, sm0_clkdiv);
  sm_config_set_clkdiv(&c_sm1, sm1_clkdiv);

  sm_config_set_in_pins(&c_sm0, in_base);
  sm_config_set_jmp_pin(&c_sm1, jmp_pin);

  sm_config_set_sideset(&c_sm0, 1, false, false);
  sm_config_set_sideset_pins(&c_sm0, sideset_base);

  pio_gpio_init(pio, sideset_base);
  pio_sm_set_consecutive_pindirs(pio, sm0, sideset_base, 1, true);

  sm_config_set_fifo_join(&c_sm0, PIO_FIFO_JOIN_RX);
  sm_config_set_fifo_join(&c_sm1, PIO_FIFO_JOIN_RX);

  pio_sm_init(pio, sm0, sm0_offset, &c_sm0);
  pio_sm_init(pio, sm1, sm1_offset, &c_sm1);

  for (uint32_t sm_i = 0; sm_i < 2; sm_i++)
  {
    for (uint32_t dma_i = 0; dma_i < SM_DMA_COUNT; dma_i++)
    {
      dma_chan_sm[sm_i][dma_i] = dma_claim_unused_channel(true);
    }
  }

  for (uint32_t sm_i = 0; sm_i < 2; sm_i++)
  {
    for (uint32_t dma_i = 0; dma_i < SM_DMA_COUNT; dma_i++)
    {
      dma_conf_sm[sm_i][dma_i] = dma_channel_get_default_config(dma_chan_sm[sm_i][dma_i]);
    }
  }

  for (uint32_t sm_i = 0; sm_i < 2; sm_i++)
  {
    for (uint32_t dma_i = 0; dma_i < SM_DMA_COUNT; dma_i++)
    {
      channel_config_set_read_increment(&dma_conf_sm[sm_i][dma_i], false);
    }
  }

  for (uint32_t sm_i = 0; sm_i < 2; sm_i++)
  {
    for (uint32_t dma_i = 0; dma_i < SM_DMA_COUNT; dma_i++)
    {
      channel_config_set_write_increment(&dma_conf_sm[sm_i][dma_i], true);
    }
  }

  for (uint32_t dma_i = 0; dma_i < SM_DMA_COUNT; dma_i++)
  {
    channel_config_set_dreq(&dma_conf_sm[0][dma_i], pio_get_dreq(pio, sm0, false));
  }
  for (uint32_t dma_i = 0; dma_i < SM_DMA_COUNT; dma_i++)
  {
    channel_config_set_dreq(&dma_conf_sm[1][dma_i], pio_get_dreq(pio, sm1, false));
  }

  for (uint32_t sm_i = 0; sm_i < 2; sm_i++)
  {
    for (uint32_t dma_i = 0; dma_i < SM_DMA_COUNT; dma_i++)
    {
      if (dma_i == SM_DMA_COUNT - 1)
      {
        channel_config_set_chain_to(&dma_conf_sm[sm_i][dma_i], dma_chan_sm[sm_i][0]);
      }
      else
      {
        channel_config_set_chain_to(&dma_conf_sm[sm_i][dma_i], dma_chan_sm[sm_i][dma_i + 1]);
      }
    }
  }

  for (uint32_t sm_i = 0; sm_i < 2; sm_i++)
  {
    for (uint32_t dma_i = 0; dma_i < SM_DMA_COUNT; dma_i++)
    {
      dma_channel_set_irq0_enabled(dma_chan_sm[sm_i][dma_i], true);
    }
  }

  irq_set_exclusive_handler(DMA_IRQ_0, isr0);
  irq_set_enabled(DMA_IRQ_0, true);

  for (uint32_t dma_i = 0; dma_i < SM_DMA_COUNT; dma_i++)
  {
    if (dma_i == 0)
    {
      dma_channel_configure(dma_chan_sm[0][dma_i], &dma_conf_sm[0][dma_i], sm_buffer[0][dma_i], &pio->rxf[sm0], SM_BUFFER_SIZE, true);
    }
    else
    {
      dma_channel_configure(dma_chan_sm[0][dma_i], &dma_conf_sm[0][dma_i], sm_buffer[0][dma_i], &pio->rxf[sm0], SM_BUFFER_SIZE, false);
    }
  }
  for (uint32_t dma_i = 0; dma_i < SM_DMA_COUNT; dma_i++)
  {
    if (dma_i == 0)
    {
      dma_channel_configure(dma_chan_sm[1][dma_i], &dma_conf_sm[1][dma_i], sm_buffer[1][dma_i], &pio->rxf[sm1], SM_BUFFER_SIZE, true);
    }
    else
    {
      dma_channel_configure(dma_chan_sm[1][dma_i], &dma_conf_sm[1][dma_i], sm_buffer[1][dma_i], &pio->rxf[sm1], SM_BUFFER_SIZE, false);
    }
  }

  pio_sm_set_enabled(pio, sm0, true);
  pio_sm_set_enabled(pio, sm1, true);
}
//do not put extra stuff in core1
void loop1()
{
  for (uint32_t dma_i = 0; dma_i < SM_DMA_COUNT; dma_i++)
  {
    if (sm_buffer_full[dma_i] == true)
    {
      for (uint32_t data_i = 0; data_i < SM_BUFFER_SIZE; data_i++)
      {
        queue_try_add(&sm0_queue, &sm_buffer[0][dma_i][data_i]);
        queue_try_add(&sm1_queue, &sm_buffer[1][dma_i][data_i]);
      }
      sm_buffer_full[dma_i] = false;
    }
  }
}

void isr0()
{
  for (uint32_t dma_i = 0; dma_i < SM_DMA_COUNT; dma_i++)
  {
    if (dma_channel_get_irq0_status(dma_chan_sm[0][dma_i]) && dma_channel_get_irq0_status(dma_chan_sm[1][dma_i]))
    {
      sm_buffer_full[dma_i] = true;
      dma_channel_configure(dma_chan_sm[0][dma_i], &dma_conf_sm[0][dma_i], sm_buffer[0][dma_i], &pio->rxf[sm0], SM_BUFFER_SIZE, false);
      dma_channel_configure(dma_chan_sm[1][dma_i], &dma_conf_sm[1][dma_i], sm_buffer[1][dma_i], &pio->rxf[sm1], SM_BUFFER_SIZE, false);
      dma_channel_acknowledge_irq0(dma_chan_sm[0][dma_i]);
      dma_channel_acknowledge_irq0(dma_chan_sm[1][dma_i]);
    }
  }
}

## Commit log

2026-07-20 Add note about I2C pin wiring issue
2026-07-20 Document I2C pin wiring issue in BUG file
2026-07-20 Add note about I2C pins wiring issue
    Documented a wiring issue with I2C pins.
